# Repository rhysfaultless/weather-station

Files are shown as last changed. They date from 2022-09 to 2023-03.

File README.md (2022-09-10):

# weather-station-ros2

---

## Purpose and background

I want a rainfall and termperature tracking system for my home.
I would also like to have this data as ROS topics to use for later automation projects.
There are several tutorials and projects detailing similar setups, but none that then convert the data into ROS.

## References

- [Hardware ideas](https://projects.raspberrypi.org/en/projects/build-your-own-weather-station/5) from a Raspberry Pi tutorial.
- [Hardware ideas](https://learn.sparkfun.com/tutorials/weather-meter-hookup-guide/all) from a Sparkfun tutorial.
- [micro-ROS supported hardware](https://micro.ros.org/docs/overview/hardware/) instead of using a computer like a Raspberry Pi.

## Install Prettier for text formatting of README files

1.  Clone the repository
2.  Open a terminal shell to the cloned repository
3.  Make sure you have Node.js installed by running `node -v`.
    Download and install [Node.js](https://nodejs.org/).
4.  In the terminal, run `npm install`.
    This will install the dependencies listed in the file _package.json_.
5.  From now on you can just run `npx prettier --write <filepath>` to format a file.
    For example; to format the README in the electrical folder:
    ```
    npx prettier --write electrical/README.md
    ```
    This will format the file according to the rules listed in the file _.prettierrc.json_.
    You will not need to run through the other steps again.

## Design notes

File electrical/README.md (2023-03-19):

# weather-station-ros2, Electrical

---

## Tools

- Electrical CAD files were created using [KiCAD](https://www.kicad.org/).
  KiCad is free to use, but they do accept [donations](https://www.kicad.org/donate/faq/).
- Components were chosen using web catalogs for [Adafruit](https://www.adafruit.com/), [Sparkfun](https://www.sparkfun.com/), [Digi-Key](https://www.digikey.ca/), [Mouser](https://mouser.ca/), and [Octopart](https://octopart.com/).

## Parts List, Raspberry Pi Variant

| Project Item Number| Schematic ID | Quantity | Description | Manufacturer | Manufacturer Item # | Distributor | Distributor # |
| :--: | :---: | :---: | :--- | :--- | :--- | :--- | :--- |
| 1001 | A1 | 1 | Raspberry Pi 3 B+ (End-of-life. I used this because because I had several on-hand) <br/> _Alternative: Raspberry Pi 4 B_ | Raspberry Pi | Raspberry Pi 3 B+ | End-of-life | |
| 1002 | | 1 | Raspberry Pi prototyping board | Adafruit | [2310](https://www.adafruit.com/product/2310) | Digi-Key | [1528-1369-ND](https://www.digikey.ca/en/products/detail/adafruit-industries-llc/2310/5629417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) |
| 1003 | A2 | 1 | Sensor (temperature) | Adafruit | [5027](https://www.adafruit.com/product/5027) | Digi-Key | [1528-5027-ND](https://www.digikey.ca/en/products/detail/adafruit-industries-llc/5027/14291401) |
| 1004 | | 3 | Header, Female, 6 Position | Adam Tech | RS1-06-G | Digi-Key | [2057-RS1-06-G-ND](https://www.digikey.ca/en/products/detail/adam-tech/RS1-06-G/9832050) |
| 1005 | D1 | 1 | LED, Amber, 2.1 V | Cree | C503B-ACN-CY0Z0252-030 | Digi-Key | [C503B-ACN-CY0Z0252-030CT-ND](https://www.digikey.ca/en/products/detail/creeled-inc/C503B-ACN-CY0Z0252-030/2341518) |
| 1006 | R1 | 1 | Resistor, 147 Ω, 0.25 W | Yageo | MFR-25FBF52-147R | Digi-Key | [147XBK-ND](https://www.digikey.ca/en/products/detail/yageo/MFR-25FBF52-147R/12829) |
| 1007 | SW1 | 1 | Rain Sensor | Misol | MS-WH-SP-RG | AliExpress  | [1000001838878](https://www.aliexpress.com/i/1000001838878.html) |
| 1008 | | 1 | PCB Terminal (RJ11) | Sparkfun | [BOB-14021](https://www.sparkfun.com/products/14021) | Digi-Key | [1568-1440-ND](https://www.digikey.ca/en/products/detail/sparkfun-electronics/BOB-14021/6228638) |
| 1009 | | 1 | Terminal (RJ11) | Assman Components | A-2014-1-4-N-T-R | Digi-Key | [AE10395-ND](https://www.digikey.ca/en/products/detail/assmann-wsw-components/A-2014-1-4-N-T-R/2183646) |
| 1010 | | 1 | RJ11 bulkhead connector | Cliff | CP30623 | Digi-Key | [3185-CP30623-ND](https://www.digikey.ca/en/products/detail/cliff-electronic-components-ltd/CP30623/13688238) |
| 1011 | | 1 | Cable, RJ11 | Amphenol | MP-5FRJ11STWS-001 | Digi-Key | [3272-MP-5FRJ11STWS-001-ND](https://www.digikey.ca/en/products/detail/amphenol-cables-on-demand/MP-5FRJ11STWS-001/13877699) |
| 1012 | | 1 | AC power bulkhead connector | AdamTech | IEC-A-1 | Digi-Key | [2057-IEC-A-1-ND](https://www.digikey.ca/en/products/detail/adam-tech/IEC-A-1/9832381) |
| 1013 | | 1 | AC-DC Power Supply (5 V, 3 A) | Mornsun | LD03-23B05WR2 | Digi-Key | [2725-LD03-23B05WR2-ND](https://www.digikey.ca/en/products/detail/mornsun-america-llc/LD03-23B05WR2/13968647) |
| 1014 | | 2 | Quick disconnect, (.187" X .032") | Panduit | DNF18-187FIB | Digi-Key | |
| 1015 | | 1 | Fuse Holder | Eaton | BK/HTB-22I-R | Digi-Key | [283-2851-ND](https://www.digikey.ca/en/products/detail/eaton-electronics-division/BK-HTB-22I-R/1024104) |
| 1016 | | 1 | Fuse (2.5 A, Ø6.3 mm X 32 mm) | Schurter | 8020.5015 | Digi-Key | [486-3090-ND](https://www.digikey.ca/en/products/detail/schurter-inc/8020-5015/5051479) |

## Parts List, ESP32 variant

I have not designed, built, or tested any aspect of the ESP32 variant.
This parts list is intended as a place to organize hardware ideas, and not as a proof of concept.

| Description | Manufacturer | Manufacturer Item # | Distributor | Distributor # |
| :--- | :--- | :--- | :--- | :--- |
| Microcontroller ( ESP32 ) | Adafruit | [3405](https://www.adafruit.com/product/3405) | Digi-Key | [1528-2181-ND](https://www.digikey.ca/en/products/detail/adafruit-industries-llc/3405/7244967) |

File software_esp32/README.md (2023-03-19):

# weather-station-ros2, Software

---

## Tools

- Git and GitHub
- VS Code
- [ESP32-IDF](https://github.com/espressif/vscode-esp-idf-extension/blob/master/docs/tutorial/install.md) (VS Code Extension)

## Resources

- [ESP32 documentation](https://docs.espressif.com/projects/esp-idf/en/latest/esp32/get-started/)
- [micro-ROS explanation by Bosch](https://www.bosch.com/stories/bringing-robotics-middleware-onto-tiny-microcontrollers/)

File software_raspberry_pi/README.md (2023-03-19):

# weather-station-ros2, Software

---

## Tools

- Git and GitHub
- VS Code
- [VS Code extension for Remote development](https://code.visualstudio.com/docs/remote/ssh)
- [Ubuntu Server 22.04](https://ubuntu.com/download/raspberry-pi)
- [Raspberry Pi Imager](https://www.raspberrypi.com/software/)
- [gpiozero](https://gpiozero.readthedocs.io/en/stable/index.html)
  - Install with `sudo apt install python3-gpiozero`

## Resources

- [ROS2 on Raspberri Pi](https://docs.ros.org/en/foxy/How-To-Guides/Installing-on-Raspberry-Pi.html)
- [Raspberry Pi Foundation](https://projects.raspberrypi.org/en/projects/build-your-own-weather-station/)

## I tried, but found issues

- installing dependencies for [MariaDB Connector](https://mariadb.com/docs/skysql/connect/programming-languages/python/install/)

# Useful commands for MySQL

| Command Type | Command | Purpose |
| :--- | :--- | :--- |
| bash | `sudo mysql;` | enters the MySQL terminal |
| MySQL | `use weather;` | connect to the `weather` database |
| MySQL | `show full tables;` | list all the tables inside the current database |
| MySQL | `show columns in WeatherMeasurements;` | lists the columens in the table `WeatherMeasurements` |
| MySQL | `select * from WeatherMeasurements;` | lists all rows and related data from the table `WeatherMeasurements` |
| MySQL | `delete from WeatherMeasurements;` | deletes all rows from the table `WeatherMeasurements` |

# TODO hardware to purchase

| Quantity  | Description | Manufacturer | Item Number | DigiKey |
| :--- | :--- | :--- | :--- | :--- |
| 1 | Breadboard | Adafruit | 2310 | [1528-1369-ND](https://www.digikey.ca/en/products/detail/adafruit-industries-llc/2310/5629417) |
| 2 | 0.1" header, female, 1 X 6 | Adam Tech | RS1-06-G | [2057-RS1-06-G-ND](https://www.digikey.ca/en/products/detail/adam-tech/RS1-06-G/9832050) | 
| 1 | Terminal (RJ12) | Adam Tech | MTJ-661X1 | [2057-MTJ-661X1-ND](https://www.digikey.ca/en/products/detail/adam-tech/MTJ-661X1/9832264) |

# Installation

1.  Insert a micro-SD card in another computer, and open Raspberry Pi Imager (tested with v1.7.3).
    - Select the card from the devices
    - Select the OS as `Ubuntu Desktop 22.04.2 LTS, 64 bit`
    - click Write
2.  Once completed, insert the micro-SD into the Raspberry Pi, connect the Pi to Ethernet, and then turn the Pi on.
3.  Ubuntu installation and setup:
    - Location (_Toronto_)
    - Keyboard input (_US English_)
    - Hostname (_rp-001_)
    - Username (_administrator_)
    - Password (_****_)
    - The Pi will reboot, and then ask you to login
    - Skip the Google / Microsoft / Ubuntu login
    - Skip the Ubuntu Pro option
    - Choose whether to send system information to Canonical (_No_)
    - Choose whether to allow location services (_Yes_)
    - Select Done
4.  Optional, connect to a Wi-Fi network, or continue to use the hardwired network.    
5.  Update the system by opening a terminal, and running:
    ```
    sudo apt update
    sudo apt upgrade
    ```
6.  Install VS Code:
    - Open Firefox
    - Go to https://code.visualstudio.com/download
    - Download the _.deb_ for Ubuntu ARM64 (_v1.75.1_)
    - Once downloaded, double-click the file and open it with Software Installer
    - Allow it to install
    - Delete the _.deb_ from _~/Downloads_
7.  Install and configure Git by opening a terminal, and running:
    ```
    sudo apt install git
    git --version
    git config --global user.name <your user name here, without angle braces>
    git config --global user.email <your email here, without angle braces>
    ```
8.  Configure VS Code
    - Open VS Code
    - Open the Extensions panel on the left
    - Install _Git Graph_
    - Install _GitLens_
    - Install _Python_
9.  Clone this repository:
    - In the VS Code terminal:
      ```
      cd ~/Documents
      git clone https://github.com/rhysfaultless/weather-station-ros2.git
      ```

      Note: VS Code will request permission to access GitHub it this is the first use of GitHub + VS Code
    - File → Open Folder ...
    - Navigate to _~/Documents/weather-station-ros2.git_ and select _Open_
10. Install libraries and tools related to this repository, by running these lines in a terminal:
    1.  Python's pip3
        ```
        sudo apt install python3-pip
        sudo pip3 install --upgrade setuptools
        ```
    2.  [gpiozero](https://gpiozero.readthedocs.io/en/stable/index.html)
        ```
        sudo apt install python3-gpiozero
        ```
        - NOTE: this reqquires the _lgpio_ library to map cammands to the physical hardware pins.
    3.  [lgpio](https://ubuntu.com/tutorials/gpio-on-raspberry-pi#1-overview)
        ```
        sudo apt install python3-lgpio
        ```
        - [Manual from Ubuntu](https://manpages.ubuntu.com/manpages/jammy/man3/lgpio.3.html)
        - [Manual from PyPi](http://abyz.me.uk/lg/py_lgpio.html)
    4.  Give the _administrtor_ user permissions for the GPIO pins, and restart the Raspberry Pi
        ```
        sudo add user administrator dialout
        sudo reboot
        ```
    5.  [MySQL Connector](https://www.w3schools.com/python/python_mysql_getstarted.asp)
        ```
        pip3 install mysql-connector-python
        ```
    6.  [Adafruit MCP9808 library](https://learn.adafruit.com/adafruit-mcp9808-precision-i2c-temperature-sensor-guide/python-circuitpython)
        ```
        sudo pip3 install adafruit-circuitpython-mcp9808
        ```
    7.  Configure the Raspberry Pi's I2C pins using the [Raspberry Pi Configuration Tool](https://www.raspberrypi.com/documentation/computers/configuration.html)
        ```
        sudo apt-get install raspi-config
        sudo raspi-config
        ```
        - Select _Interfacing Options_
        - Select _I2C_
        - Select _Yes_
        - Select _Ok_
        - Select _Finish_
        ```
        sudo apt-get install -y python3-smbus
        sudo apt-get install -y i2c-tools
        ```
        - Test with `sudo i2cdetect -y 1`
    8.  [Adafruit's CircuitPython](https://learn.adafruit.com/building-circuitpython/linux)
        ```
        sudo add-apt-repository ppa:pybricks/ppa
        sudo apt install git gettext uncrustify cmake
        ```
    9.  [MariaDB](https://mariadb.com/kb/en/installing-mariadb-deb-files/#installing-mariadb-packages-with-apt)
        ```
        sudo apt-get install mariadb-server libmariadb3 libmariadb-dev
        ```

        -   NOTE: the MySQL / MariaDB database will be running on boot.
            You can connect to it by entering `sudo mysql` into a terminal.
        -   NOTE: SQL commands require the ; line ending syntax.
            This allows you to type multi-line commands before executing them.
        1.  `sudo mysql`
        2.  Then add a username and password:
            ```
            create user database_administrator identified by 'database_administrators_password';
            ```
            - Change `database_administrator` to whatever username you would like.
            - Change `database_administrator_password` to whatever password you would like.

        3.  Grant privileges to all users:
            ```
            grant all privileges on *.* to 'database_administrator' with grant option;
            ```
            - Change `database_administrator` to whatever username you set earlier.
        4.  Create a database:
            ```
            create database weather;
            ```
            - This new database is named `weather`
        5.  Connect to the database:
            ```
            use weather;
            ```
            - The prompt will change to `MariaDB [weather]>`
            - The prompt was `MariaDB [(none)]>`
        6.  Create a table inside the `weather` database:
            ```
            CREATE TABLE WeatherMeasurements (
            ElementIdentification BIGINT NOT NULL AUTO_INCREMENT,
            AmbientTemperature DECIMAL(6,2) NOT NULL,
            RainfallVolume DECIMAL (6,2) NOT NULL,
            TimestampValue TIMESTAMP NOT NULL DEFAULT CURRENT_TIMESTAMP,
            PRIMARY KEY ( ElementIdentification )
            );
            ```
            - This is a table named `WeatherMeasurements`.
              It has columns of:
              - `ElementIdentification`
              - `AmbientTemperature`
              - `RainfallVolumen`
              - `TimestampValue`
            - The `ElementIdentification` column is set as the primary key.
        7.  Confirm that the table and columns were configured:
            ```
            show columns in WeatherMeasurements;
            ```

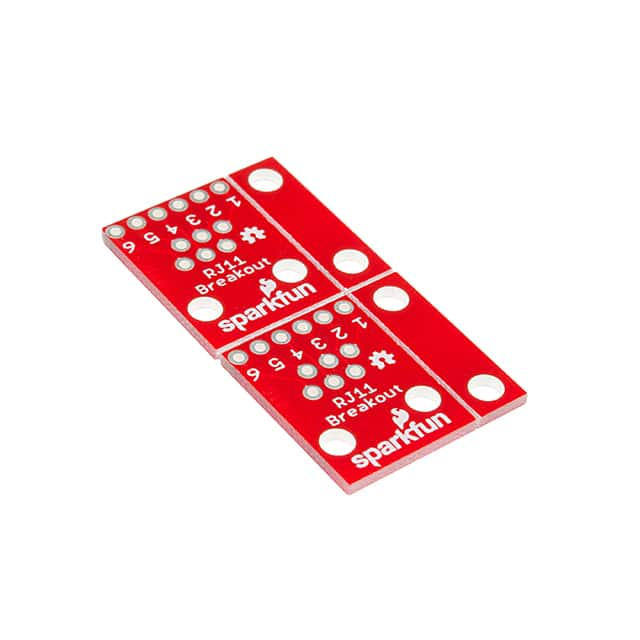
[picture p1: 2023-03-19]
documentation/1008-TDS1.jpeg

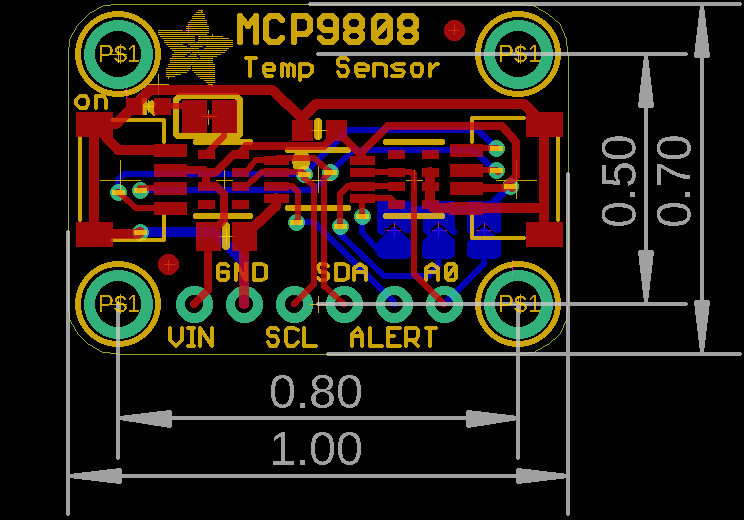
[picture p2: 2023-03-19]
documentation/1003-TDS3.png

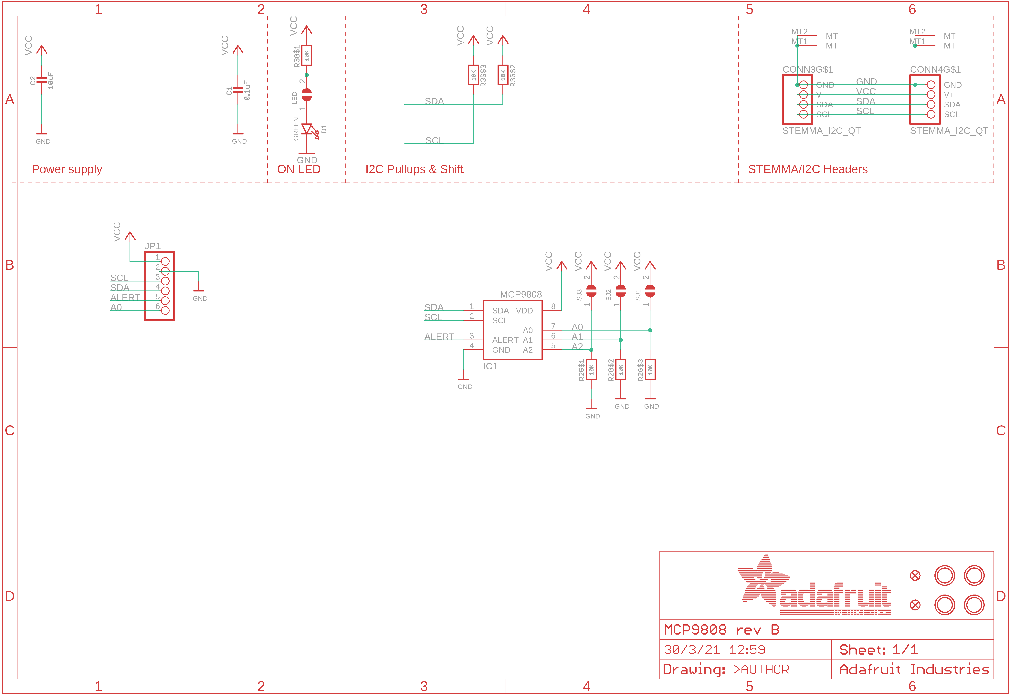
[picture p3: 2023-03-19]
documentation/1003-TDS2.png

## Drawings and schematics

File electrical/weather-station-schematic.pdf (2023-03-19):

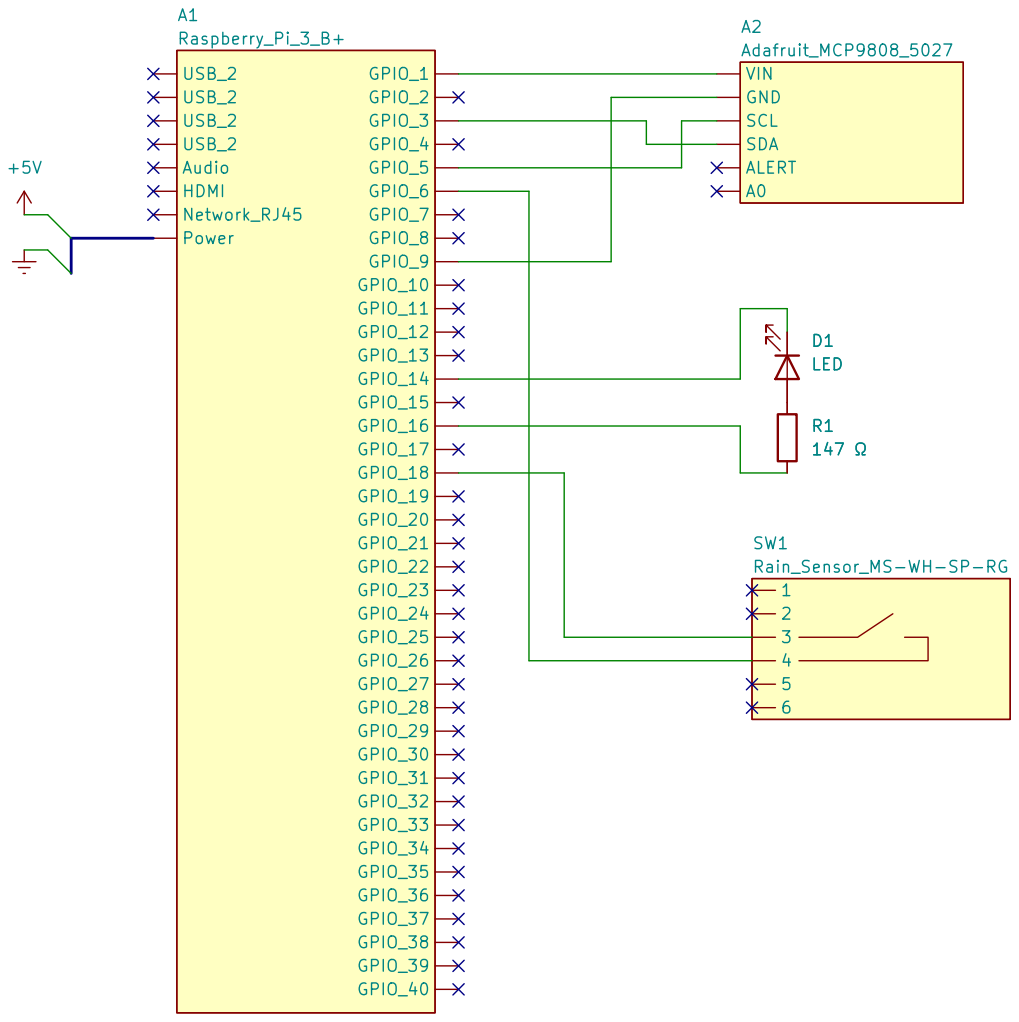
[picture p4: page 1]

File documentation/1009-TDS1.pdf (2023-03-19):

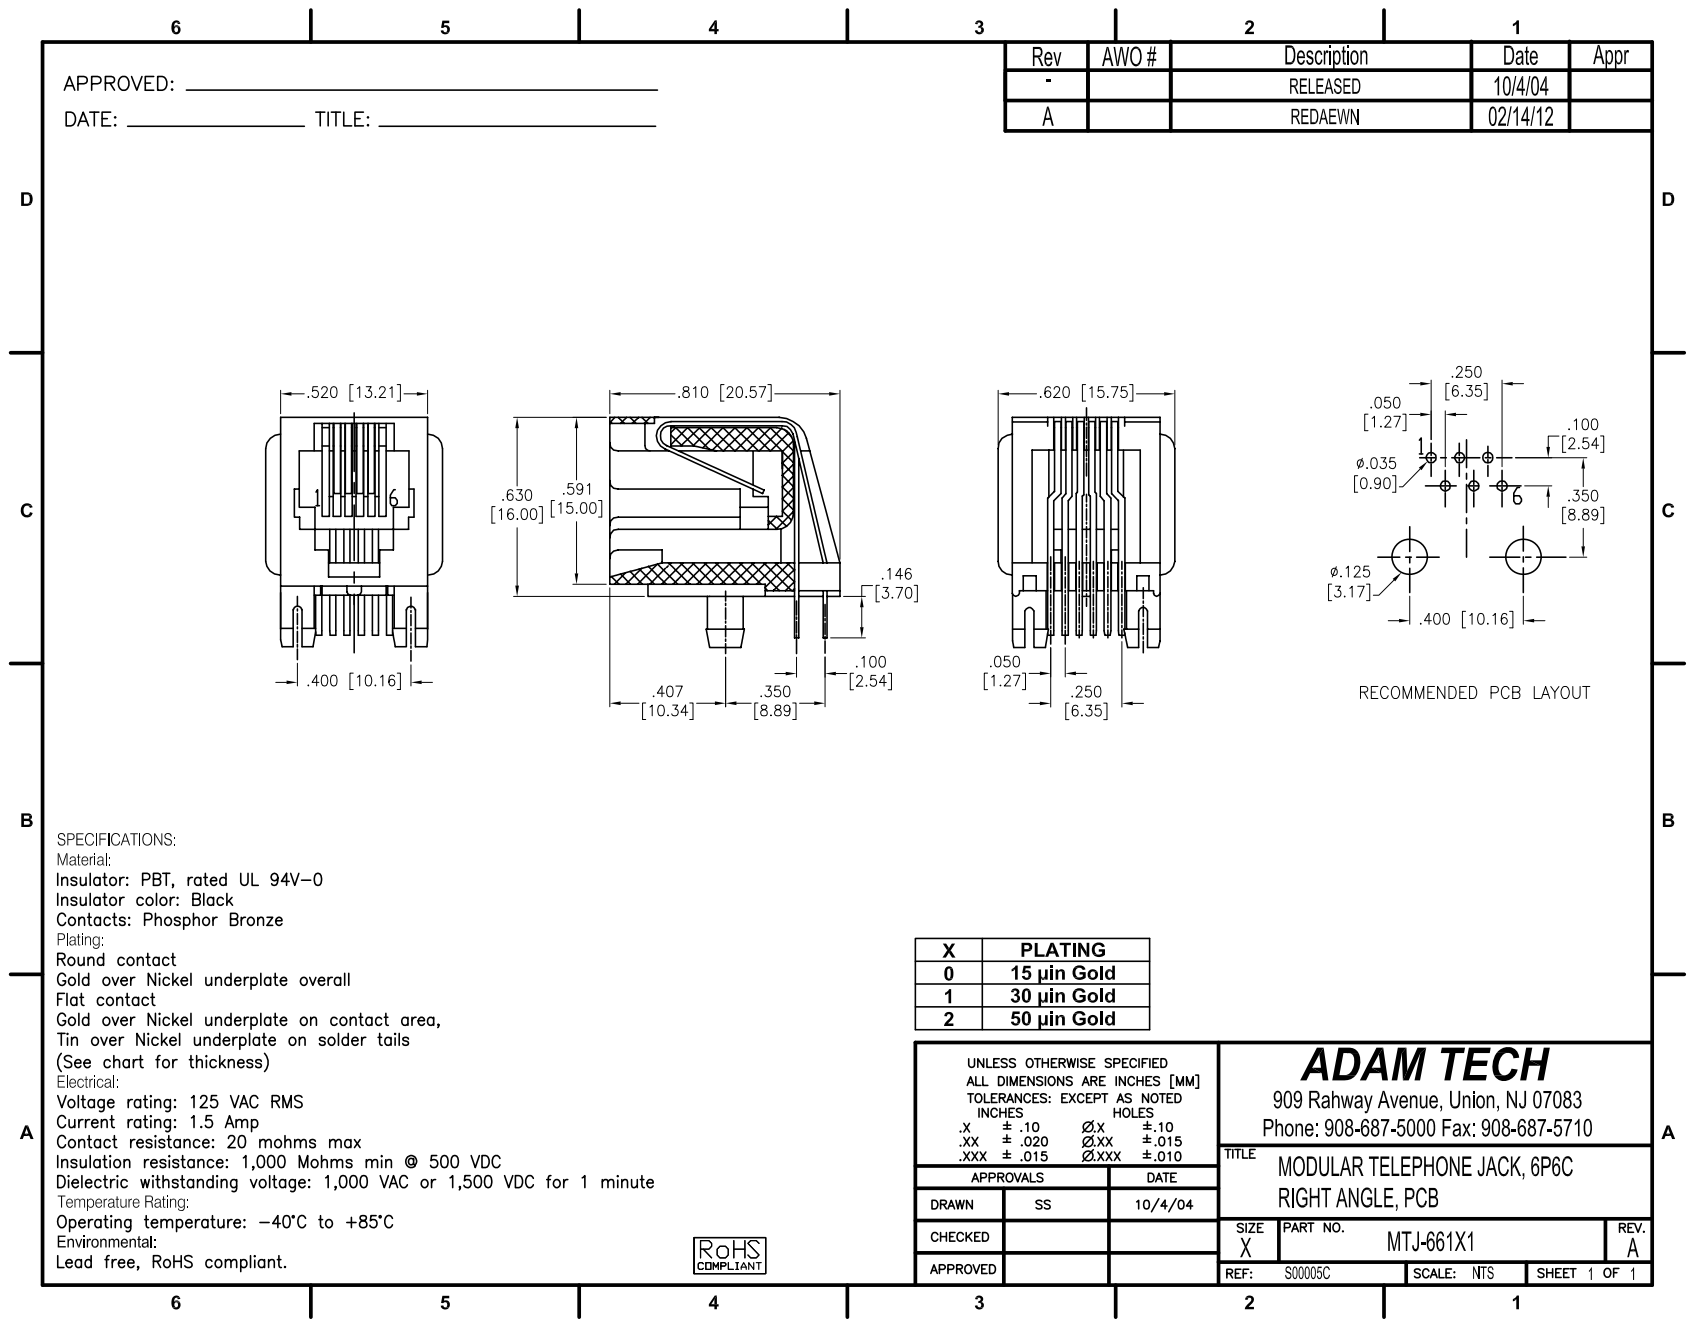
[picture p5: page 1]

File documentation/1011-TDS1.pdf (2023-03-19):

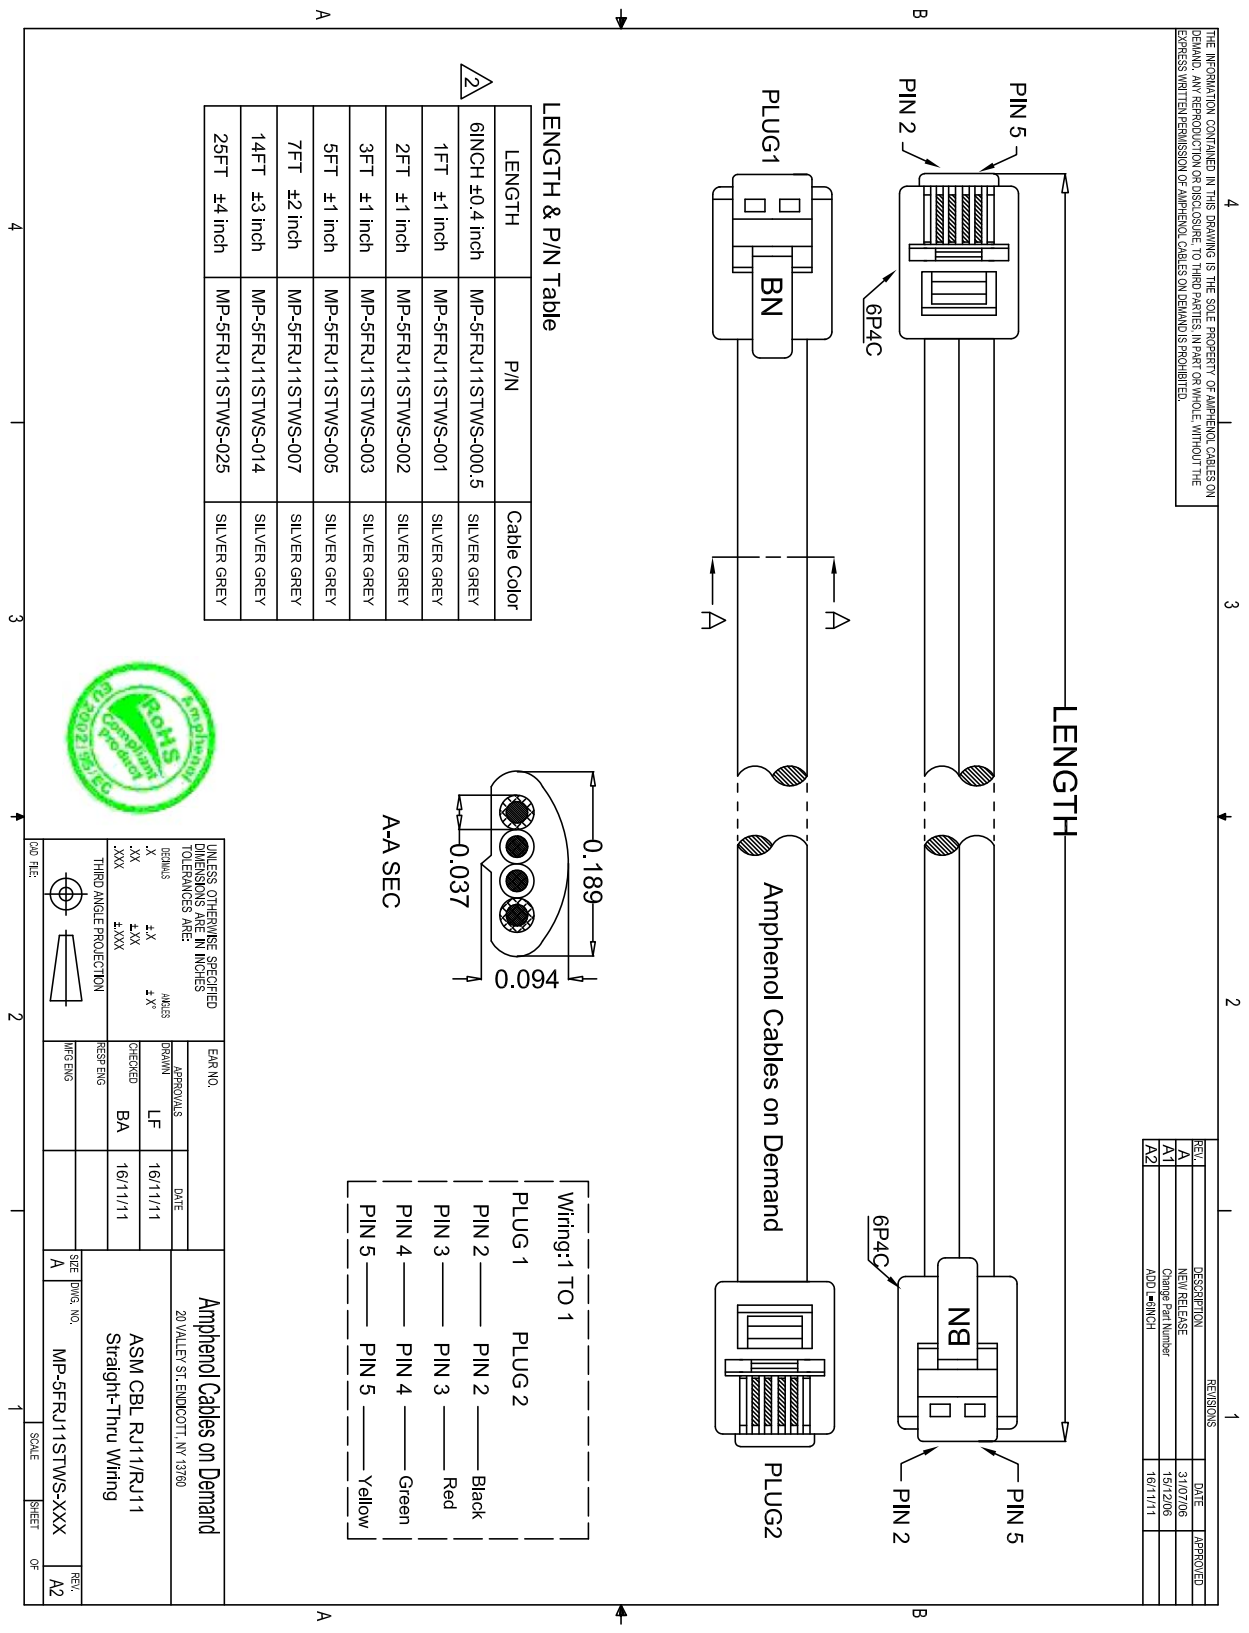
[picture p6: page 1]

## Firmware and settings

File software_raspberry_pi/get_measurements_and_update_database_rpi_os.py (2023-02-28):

import gpiozero # for GPIO pin control
import time # for database timestamp and LED blinking
import mysql.connector # for database updates
import threading # for running LED and temperature processes in the background
import board # for temperature measurement
import busio # for temperature measurement
import adafruit_mcp9808 # for temperature measurement

rain_sensor_gpio_pin = gpiozero.Button("BOARD18")
sampling_interval_time = 900 # measurements taken every 900 seconds (15 minutes)
volume_per_rainfall_bucket = 0.2794 # millimetres^3 per bucket tip. Refer to hardware datasheet.
rainfall_buckets_counted = 0
rainfall_volume_counted = 0
temperature_list = []
average_temperature = 0


def led_blink():
    led_gpio_pin = gpiozero.LED("BOARD16")
    led_blinking_interval_on = 0.6
    led_blinking_interval_off = 5
    while True:
        led_gpio_pin.on()
        time.sleep(led_blinking_interval_on)
        led_gpio_pin.off()
        time.sleep(led_blinking_interval_off)


def rainfall_bucket_tipped():
    global rainfall_buckets_counted
    global rainfall_volume_counted
    rainfall_buckets_counted += 1
    rainfall_volume_counted = rainfall_buckets_counted * volume_per_rainfall_bucket


def reset_rainfall_buckets_counted():
    global rainfall_buckets_counted
    rainfall_buckets_counted = 0


def reset_rainfall_volume_counted():
    global rainfall_volume_counted
    rainfall_volume_counted = 0


def add_to_database():
    global rainfall_volume_counted
    global average_temperature
    weather_database = mysql.connector.connect(
        host="localhost",
        user="database_administrator",
        password="database_administrator_password",
        database="weather"
    )
    cursor = weather_database.cursor()
    # weather_measurements_table_last_row_identification = cursor.lastrowid

    timestamp_for_database = time.strftime('%Y-%m-%d %H:%M:%S')

    data_weather_element = {
        'AmbientTemperature': average_temperature,
        'RainfallVolume': rainfall_volume_counted,
        'TimestampValue': timestamp_for_database
    }

    add_weather_element = ("INSERT INTO WeatherMeasurements "
              "(AmbientTemperature, RainfallVolume, TimestampValue) "
              "VALUES (%(AmbientTemperature)s, %(RainfallVolume)s, %(TimestampValue)s)")

    # ElementIdentification is not included in data_weather_element or add_weather_element
    # This is because the table, WeatherMeasurements is configured to AutoIncrement this element

    cursor.execute(add_weather_element, data_weather_element)
    weather_database.commit()
    cursor.close()
    weather_database.close()

    print("Rainfall volume: " + str(rainfall_volume_counted) + " mm^3")
    print("Ambient temperature: " + str(average_temperature) + "°C")
    print("\r")


def add_to_temperature_list():
    global temperature_list
    global mcp
    temperature_measurement_interval = 5
    i2c = busio.I2C(board.SCL, board.SDA)
    mcp = adafruit_mcp9808.MCP9808(i2c)

    while True:
        temperature_list.append(mcp.temperature)
        time.sleep(temperature_measurement_interval)


def update_average_of_temperature_list():
    global temperature_list
    global average_temperature
    average_temperature = sum(temperature_list) / len(temperature_list)


def reset_temperature_list():
    global temperature_list
    temperature_list = []


while True:
    threaded_led_blinking = threading.Thread(target=led_blink)
    threaded_led_blinking.start()

    threaded_temperature_measurement = threading.Thread(target=add_to_temperature_list)
    threaded_temperature_measurement.start()

    while True:
        start_time = time.time()
        while time.time() <= start_time + sampling_interval_time:
            rain_sensor_gpio_pin.when_pressed = rainfall_bucket_tipped
        
        update_average_of_temperature_list()

        add_to_database()
        
        reset_rainfall_buckets_counted()
        reset_rainfall_volume_counted()
        reset_temperature_list()

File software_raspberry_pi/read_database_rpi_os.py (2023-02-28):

import datetime
import mysql.connector # for database updates


# Connect to the database
weather_database = mysql.connector.connect(
    host="localhost",
    user="database_administrator",
    password="database_administrators_password",
    database="weather"
)


# Pull the latest 672 rows of data from the database table WeatherMeasurements
cursor = weather_database.cursor()
sql_statement = "select * from WeatherMeasurements order by ElementIdentification desc limit 672;"
cursor.execute(sql_statement)
database_rows = cursor.fetchall()


# The current time difference should be less than 900 seconds, since this is the intended database update interval
current_time = datetime.datetime.now()
latest_database_time = database_rows[0][3]
current_time_difference = (current_time - latest_database_time).total_seconds()


# Only structure the data if a row was added to the database within the last 15 minutes
if current_time_difference > (900 * 1.1):
    print("The database has not updated in the past 15 minutes")
else:
    # Messages are being added to the database in ~15 minute intervals

    interval_additional_buffer           = 10 # seconds
    seconds_to_remove                    = 900


    expected_number_rows_15_minutes      = 1
    interval_15_minutes                  = 900 - seconds_to_remove + interval_additional_buffer # seconds
    database_temperature_list_15_minutes = []
    average_temperature_15_minutes       = None
    database_rainfall_list_15_minutes    = []
    total_rainfall_15_minutes          = None

    expected_number_rows_1_hour          = 4
    interval_1_hour                      = 3600 - seconds_to_remove + interval_additional_buffer # seconds
    database_temperature_list_1_hour     = [] #   4 rows   #   3600 seconds
    average_temperature_1_hour           = None
    database_rainfall_list_1_hour        = []
    total_rainfall_1_hour              = None

    expected_number_rows_1_day           = 96
    interval_1_day                       =  86400 - seconds_to_remove + interval_additional_buffer # seconds
    database_temperature_list_1_day      = [] #  96 rows   #  86400 seconds
    average_temperature_1_day            = None
    database_rainfall_list_1_day         = []
    total_rainfall_1_day               = None

    expected_number_rows_2_days          = 192
    interval_2_days                      = 172800 - seconds_to_remove + interval_additional_buffer # seconds
    database_temperature_list_2_days     = [] # 192 rows   # 172800 seconds
    average_temperature_2_days           = None
    database_rainfall_list_2_days        = []
    total_rainfall_2_days              = None

    expected_number_rows_3_days          = 288
    interval_3_days                      = 259200 - seconds_to_remove + interval_additional_buffer # seconds
    database_temperature_list_3_days     = [] # 288 rows   # 259200 seconds
    average_temperature_3_days           = None
    database_rainfall_list_3_days        = []
    total_rainfall_3_days              = None

    expected_number_rows_7_days          = 672
    interval_7_days                      = 604800 - seconds_to_remove + interval_additional_buffer # seconds
    database_temperature_list_7_days     = [] # 672 rows   # 604800 seconds
    average_temperature_7_days           = None
    database_rainfall_list_7_days        = []
    total_rainfall_7_days              = None


    # Check the times for each row, and only add the append a list it the row's timestamp is within the accepted range.
    # This is checking for database lapses / outages
    for database_row in database_rows:
        database_row_time_difference = (latest_database_time - database_row[3]).total_seconds()
        if database_row_time_difference > interval_7_days:
            print("Error: This row of the database is older than the 7 day interval")
            break
        
        elif (database_row_time_difference <= interval_7_days):
            database_temperature_list_7_days.append(database_row[1])
            database_rainfall_list_7_days.append(database_row[2])
            
            if (database_row_time_difference <= interval_3_days):
                database_temperature_list_3_days.append(database_row[1])
                database_rainfall_list_3_days.append(database_row[2])
                
                if (database_row_time_difference <= interval_2_days):
                    database_temperature_list_2_days.append(database_row[1])
                    database_rainfall_list_2_days.append(database_row[2])
                    
                    if (database_row_time_difference <= interval_1_day):
                        database_temperature_list_1_day.append(database_row[1])
                        database_rainfall_list_1_day.append(database_row[2])
                        
                        if (database_row_time_difference <= interval_1_hour):
                            database_temperature_list_1_hour.append(database_row[1])
                            database_rainfall_list_1_hour.append(database_row[2])
                            
                            if (database_row_time_difference <= interval_15_minutes):
                                database_temperature_list_15_minutes.append(database_row[1])
                                database_rainfall_list_15_minutes.append(database_row[2])

    # Calculate the average temperatures and rainfall volumes using the compiled lists
    if len(database_temperature_list_15_minutes) >= (expected_number_rows_15_minutes - 1):
        average_temperature_15_minutes = sum(database_temperature_list_15_minutes) / len(database_temperature_list_15_minutes)
        total_rainfall_15_minutes = sum(database_rainfall_list_15_minutes)

        if len(database_temperature_list_1_hour) >= (expected_number_rows_1_hour - 1):
            average_temperature_1_hour = sum(database_temperature_list_1_hour) / len(database_temperature_list_1_hour)
            total_rainfall_1_hour = sum(database_rainfall_list_1_hour)
        
            if len(database_temperature_list_1_day) >= (expected_number_rows_1_day - 1):
                average_temperature_1_day = sum(database_temperature_list_1_day) / len(database_temperature_list_1_day)
                total_rainfall_1_day = sum(database_rainfall_list_1_day)
        
                if len(database_temperature_list_2_days) >= (expected_number_rows_2_days - 1):
                    average_temperature_2_days = sum(database_temperature_list_2_days) / len(database_temperature_list_2_days)
                    total_rainfall_2_days = sum(database_rainfall_list_2_days)

                    if len(database_temperature_list_3_days) >= (expected_number_rows_3_days - 1):
                        average_temperature_3_days = sum(database_temperature_list_3_days) / len(database_temperature_list_3_days)
                        total_rainfall_3_days = sum(database_rainfall_list_3_days)
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

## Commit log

2023-02-28 Rainfall and temperature programs, raspberry pi (#1)
    * Added programs for reading temperature and rainfall sensors.
    * Added programs for updating a MariaDB database with sensor data every 15 minutes ( 5 second sampling interval ).
    * Added programs for testing and troubleshooting sensors.
    * Added a software README for describing the installation process on a Raspberry Pi with Ubuntu 22.04
    * Added useful MySQL commands to the README.
2023-03-19 Electrical (#2)
    * Added 'Electrical' folder.
    * Added hardware parts list.
    * Added documentation folder and related files from the parts list.
    * KiCad, added a drawing template.
    * KiCad, added schematic symbols for Pi, MCP9808, and rain sensor.
    * KiCad, added a schematic for the Raspberry Pi variant.
    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
    [weather-station.kicad_pcb, weather-station.kicad_sch]
